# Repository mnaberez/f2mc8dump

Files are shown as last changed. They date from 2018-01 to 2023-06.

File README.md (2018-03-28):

# f2mc8dump



## Overview

Some Fujitsu F2MC-8L microcontrollers have an
external bus capability (see the [catalog](https://web.archive.org/web/20170514004456/http://www.fujitsu.com/downloads/MICRO/fme/micros/micros_2006.pdf)).
I found that the external bus can be used to dump the contents of the
internal ROM, which is not normally accessible.

A mode pin enables the external bus.  In this mode, the internal ROM is disabled and its address space is redirected
to the external bus.  I dumped the internal ROM of the several F2MC-8L microcontrollers by hooking up an external EPROM that wrote a dumping program into RAM, then jumped to RAM.  While code was executing from RAM, I changed the mode pin.  The external bus was disabled, the internal ROM was enabled, but code kept executing from RAM and dumped out the contents of the internal ROM.

## Tested

I developed this method to extract the firmware from the [Volkswagen Premium IV](https://github.com/mnaberez/vwradio) car radios made by Clarion.  These radios contain the following microcontrollers:

 - MB89623R
 - MB89625R
 - MB89677AR

I successfully extracted the internal ROM code from all of them.  I've also tried samples of the above chips from other products and was able to extract the code from them as well.

## Hardware

The hardware setup requires the F2MC-8L microcontroller be removed from the
target device. It is placed on a board with the following other components:

 - 2764 or similar parallel EPROM with dumping firmware
 - 74HCT373 transparent latch
 - 74HCT138 3-8 decoder
 - 5V TTL oscillator (1-8 MHz)
 - 5V regulator, decoupling caps, pull-up resistors, etc.

See the `hardware/` directory for details.

A logic analyzer with 9 probes (8 data lines, 1 strobe line) is required to
capture the output from the dumping hardware.

## Firmware

Assemble the dumping firmware in the `firmware/` directory using the [asf2mc8](http://shop-pdp.net/ashtml/asf2mc.htm)
assembler and burn it into the EPROM.

## Dump

Build the hardware and power it up in external bus mode (MOD0=Vcc). It will
immediately begin dumping the memory space out P30-P37 with /STROBE on P40
after each byte. It will wrap around memory and keep dumping forever. If you
capture it with a logic analyzer, you'll see the string `EXTERNALROM` from
the dumping firmware.

While power is still applied, change MOD0 to Vss. This selects the internal
ROM mode. The program will continue dumping but it will now be dumping the
internal ROM instead. Capture the output with a logic analyzer and let it
run for a couple minutes so the entire memory space is dumped several times.
Save the capture to a file.

Use the Python script under the `host/` directory to split individual
ROM images from the logic analyzer capture.

## Disassemble

After a binary has been obtained, use [f2mc8dasm](https://github.com/mnaberez/f2mc8dasm) to disassemble it.

## Author

[Mike Naberezny](https://github.com/mnaberez)

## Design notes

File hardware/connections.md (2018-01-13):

Minimum Connections
-------------------

|MB89677AR | MB89623R | Signal | Connection
|---|---|---|---
|77 | 11 | AVCC | +5V
|78 | 12 | AVR | GND
|79 | 13 | AVSS | GND
|16 | 19 | /RST | DS1813 or similar *1
|11 | 20 | MOD0 | ROM mode select *2
|12 | 21 | MOD1 | GND
|13 | 22 | X0 | 8 MHz crystal in  *3
|14 | 23 | X1 | 8 MHz crystal out *3
|15 | 24 | VSS | GND
|58 | 49 | VSS | GND
|55 | 56 | VCC | +5V

Notes:

1. Power-on reset is generated internally so /RST can be left open.
   For bench testing, a DS1813 or similar can be used to generate /RST
   from a pushbutton.

2. GND selects single chip mode (internal ROM)
   +5V selects external bus mode (external ROM)

3. Instead of a crystal, a TTL oscillator may be used.  Connect
   the output of the TTL oscillator to X0 and leave X1 open.

External ROM Connections
------------------------

Requires minimum connections above.  Set the MOD0 pin to Vcc to select
external ROM mode.

MB89677AR | MB89623R | Signal   |   Connection
----------|----------|----------|-------------------------------------------
17        | 25       |  ALE     |   74HCT373 Pin 11 CLK
18        | 26       |  /RD     |   2764 Pin 22 /OE
21        | 29       |  RDY     |   4.7K pull-up resistor to Vcc
25        | 33       |  A15     |   74HCT138 Pin 3 C
26        | 34       |  A14     |   74HCT138 Pin 2 B
27        | 35       |  A13     |   74HCT138 Pin 1 A
28        | 36       |  A12     |   2764 Pin 2  A12
29        | 37       |  A11     |   2764 Pin 23 A11
30        | 38       |  A10     |   2764 Pin 21 A10
31        | 39       |  A9      |   2764 Pin 24 A9
32        | 40       |  A8      |   2764 Pin 25 A8
33        | 41       |  AD7     |   74HCT373 Pin 18 8D  and  2764 Pin 19 D7
34        | 42       |  AD6     |   74HCT373 Pin 17 7D  and  2764 Pin 18 D6
35        | 43       |  AD5     |   74HCT373 Pin 14 6D  and  2764 Pin 17 D5
36        | 44       |  AD4     |   74HCT373 Pin 13 5D  and  2764 Pin 16 D4
37        | 45       |  AD3     |   74HCT373 Pin 8 4D   and  2764 Pin 15 D3
38        | 46       |  AD2     |   74HCT373 Pin 7 3D   and  2764 Pin 13 D2
39        | 47       |  AD1     |   74HCT373 Pin 4 2D   and  2764 Pin 12 D1
40        | 48       |  AD0     |   74HCT373 Pin 3 1D   and  2764 Pin 11 D0

```
74HCT373:
    1  /OE  Tie to GND
    2  1Q   2764 Pin 10 A0
    5  2Q   2764 Pin 9  A1
    6  3Q   2764 Pin 8  A2
    9  4Q   2764 Pin 7  A3
    12 5Q   2764 Pin 6  A4
    15 6Q   2764 Pin 5  A5
    16 7Q   2764 Pin 4  A6
    19 8Q   2764 Pin 3  A7
    10 GND
    20 Vcc

74HCT138:
    4  /G2A  Tie to GND
    5  /G2B  Tie to GND
    6  G1    Tie to Vcc
    7  Y7    2764 Pin 20 /CE
    8  GND
    16 Vcc

2764:
    1  Vpp  Tie to Vcc
    27 /PGM Tie to Vcc
    14 GND
    28 Vcc

TTL Oscillator:
    7  GND
    8  Output  Connect to MCU's X0 pin
    14 Vcc
```

ROM Dumping Connections
-----------------------

Requires External ROM mode connections above.

MB89677AR | MB89623R |  Signal |    Connection
----------|----------|---------|------------------
48        | 50       |  P30    |    Data Out Bit 0
47        | 51       |  P31    |    Data Out Bit 1
46        | 52       |  P32    |    Data Out Bit 2
45        | 53       |  P33    |    Data Out Bit 3
44        | 54       |  P34    |    Data Out Bit 4
43        | 55       |  P35    |    Data Out Bit 5
42        | 57       |  P36    |    Data Out Bit 6
41        | 58       |  P37    |    Data Out Bit 7
57        | 59       |  P40    |    /STROBE  *1

Notes:

1. On MB89623R, P40 is open drain and needs a 47K pull-up to Vcc.
   On MB89677AR, P40 is a normal output so no pull-up is needed.

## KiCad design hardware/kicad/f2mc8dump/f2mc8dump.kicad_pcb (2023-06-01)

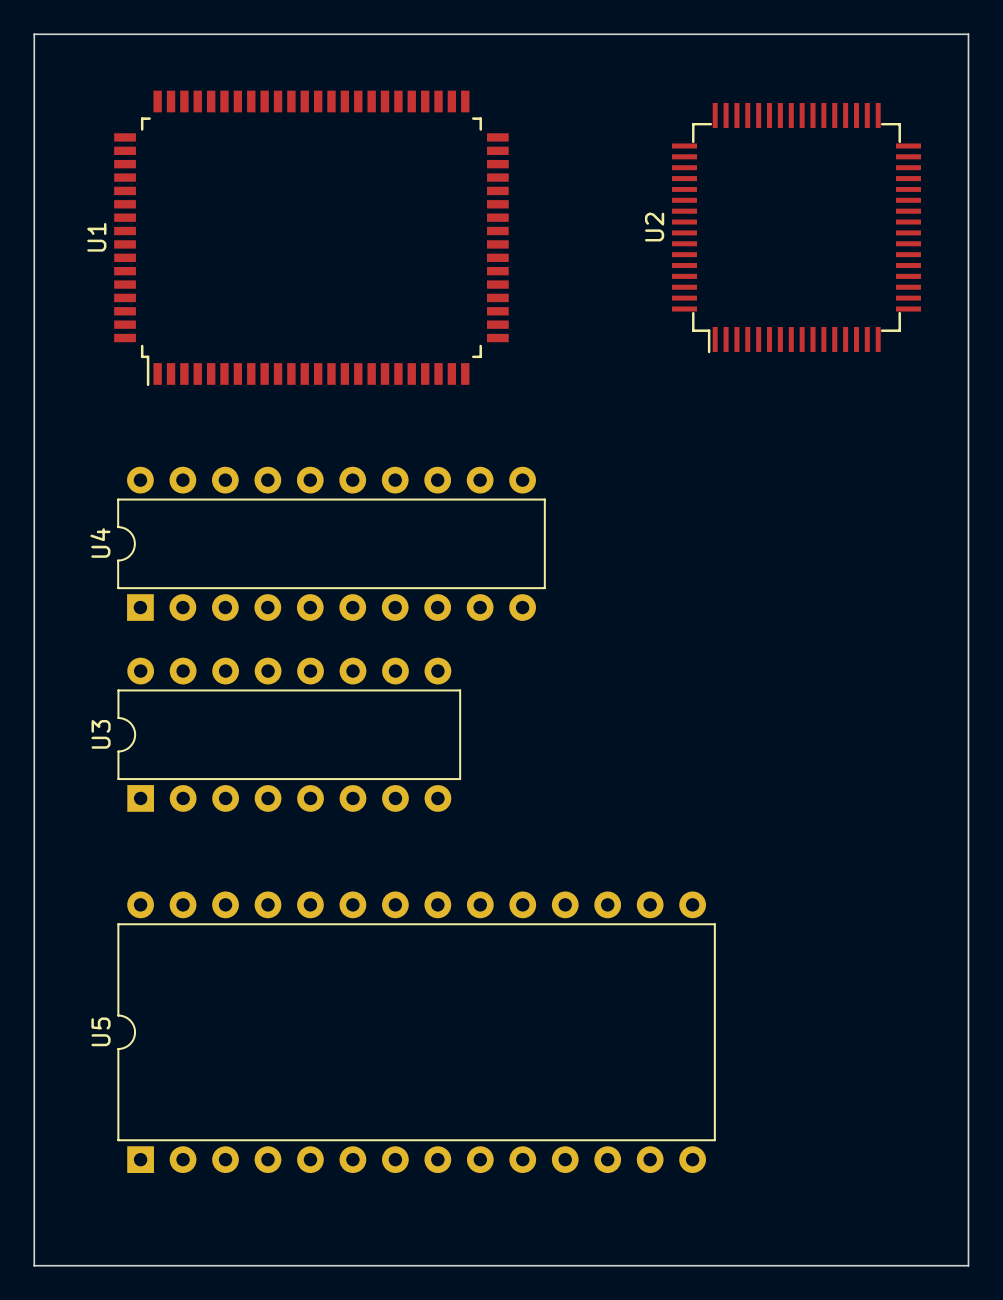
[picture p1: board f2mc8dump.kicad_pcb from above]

Board: 2 copper layers, 55.9 x 73.7 mm, 5 parts (0 on the bottom side), 30 nets, no tracks yet.

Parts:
U1: MB89677AR; PQFP-80_14x20mm_P0.8mm
U2: MB89623R; PQFP-64_12x12mm_P0.65mm
U3: 74LS138; DIP-16_W7.62mm
U4: 74LS373; DIP-20_W7.62mm
U5: 2764; DIP-28_W15.24mm

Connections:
A08: U1.32 (P10/A08), U2.40 (P10/A08)
A09: U1.31 (P11/A09), U2.39 (P11/A09)
A10: U1.30 (P12/A10), U2.38 (P12/A10), U5.21 (A10)
A11: U1.29 (P13/A11), U2.37 (P13/A11), U5.23 (A11)
A12: U1.28 (P14/A12), U2.36 (P14/A12), U5.2 (A12)
A13: U1.27 (P15/A13), U2.35 (P15/A13), U3.1 (A0)
A14: U1.26 (P16/A14), U2.34 (P16/A14), U3.2 (A1)
A15: U1.25 (P17/A15), U2.33 (P17/A15), U3.3 (A2)
AD0: U1.40 (P00/AD0), U2.48 (P00/AD0), U4.3 (D0), U5.19 (D7)
AD1: U1.39 (P01/AD1), U2.47 (P01/AD1), U4.4 (D1), U5.18 (D6)
AD2: U1.38 (P02/AD2), U2.46 (P02/AD2), U4.7 (D2), U5.17 (D5)
AD3: U1.37 (P03/AD3), U2.45 (P03/AD3), U4.8 (D3), U5.16 (D4)
AD4: U1.36 (P04/AD4), U2.44 (P04/AD4), U4.13 (D4), U5.15 (D3)
AD5: U1.35 (P05/AD5), U2.43 (P05/AD5), U4.14 (D5), U5.13 (D2)
AD6: U1.34 (P06/AD6), U2.42 (P06/AD6), U4.17 (D6), U5.12 (D1)
AD7: U1.33 (P07/AD7), U2.41 (P07/AD7), U4.18 (D7), U5.11 (D0)
ALE: U1.17 (P27/ALE), U4.11 (LE)
GND: U1.12 (MOD1), U1.15 (VSS), U1.78 (AVR), U1.79 (AVSS), U2.12 (AVR), U2.13 (AVSS), U2.21 (MOD1), U2.24 (VSS), U3.4 (E1), U3.5 (E2), U3.8 (GND), U4.1 (OE), U4.10 (GND), U5.14 (GND)
MOD0: U1.11 (MOD0), U2.20 (MOD0), U3.6 (E3)
NRD: U1.18 (P26/NRD), U2.26 (P26/NRD), U5.22 (~OE)
unnamed: U3.7 (O7), U5.20 (~CE)
unnamed: U4.2 (O0), U5.10 (A0)
unnamed: U4.5 (O1), U5.9 (A1)
unnamed: U4.6 (O2), U5.8 (A2)
unnamed: U4.9 (O3), U5.7 (A3)
unnamed: U4.12 (O4), U5.6 (A4)
unnamed: U4.15 (O5), U5.5 (A5)
unnamed: U4.16 (O6), U5.4 (A6)
unnamed: U4.19 (O7), U5.3 (A7)
VCC: U1.77 (AVCC), U2.11 (AVCC), U2.56 (VCC), U3.16 (VCC), U4.20 (VCC), U5.1 (VPP), U5.27 (~PGM), U5.28 (VCC)

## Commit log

2023-06-01 Ignore KiCad backups and preferences
2023-06-01 Start design in KiCad
    [f2mc8dump.kicad_pcb, f2mc8dump.kicad_sch]
